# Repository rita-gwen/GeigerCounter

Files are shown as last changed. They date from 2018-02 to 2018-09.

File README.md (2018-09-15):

# GeigerCounter
Firmware and software for a portable Geiger-Mueller counter. 

This project represents a portable, battery powered instrument built around Basic Nano (PIC16F87) microcontroller. The device detects 
radiation particles passing through the detector and keeps total count of them since startup and average over the 
last minute (Counts per Minute). 

This repository includes code of the firmware running on the MCU in the device and a Python application that runs on a PC, 
reads data from the device and shows a real-time plot of the counts. Basic Nano runs an embedded version of MBasic which is used to implement the main loop, power management and display functionality. There are also a couple of assembly procedures for timer ISR that actually gets the counts from the hardware and for low-level display bus handling.

The device successfully passed field testing: I took it on multiple hikes and trips around Cascades and Eastern Washington and it is reliable and performs well - I was able to detect some mildly radioactime granites and verify radiation background change with altitude. 
Features to be implemented in the next version:
 * reduced weight: use LiPO batteries instead of NiMH
 * reduce power consumption (related to the previous item)
 * Improve display visibility in full day light: LCD display is almost invisible in full sun.
 * Add multiple modes of operation: background monitoring, sample measurement
 * add data logging abilities
 * use more advanced CPU, one of ST32 CORTEX-M0 family most probably.

Please ignore the DipTrace schematic and PCB files here, they are outdated. Hardware design files are moved to CircuitMaker (https://circuitmaker.com/Projects/Details/Rita-Chupalov/Geiger). The version of DipTrace I have has too many limitations for this 
project.

Assembly.FCStd is a FreeCAD sketch of the device components fitting into the enclosure.

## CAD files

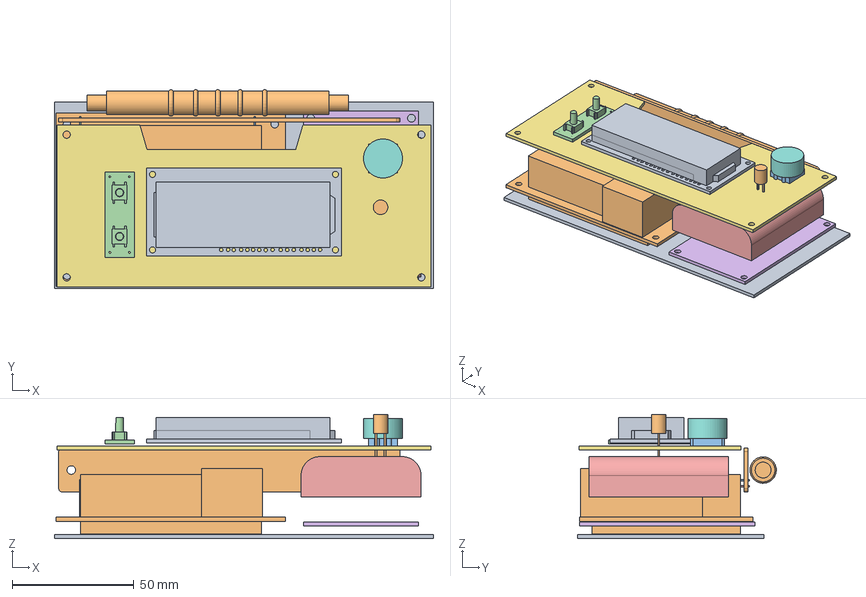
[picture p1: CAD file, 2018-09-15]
Assembly.FCStd
155.4 x 81.5 x 50.9 mm
Chassis
LongPin3
LongPin4
ShortPin3
ShortPin4
FalsePanel
Display
CountLed
DisplayButtonsAssembly

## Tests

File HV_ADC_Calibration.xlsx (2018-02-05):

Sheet: Sheet1
Vtest on 1V scale
Duty | High V | Vtest | ADC | High V | Vtest | ADC
80 | 88 | 400 | 92 | 90.4 | 464 | 91
100 | 94 | 440 | 100 | 98.4 | 504 | 99
120 | 104 | 480 | 106 | 105.6 | 536 | 106
150 | 112 | 520 | 119 | 117.6 | 600 | 119
170 | 116 | 560 | 123 | 122.4 | 624 | 124
200 | 124 | 600 | 130 | 129.2 | 656 | 130
220 | 128 | 640 | 133 | 132 | 672 | 134
250 | 136 | 640 | 139 | 137.6 | 704 | 139
275 | 140 | 680 | 144 | 142.4 | 728 | 144
300 | 144 | 680 | 148 | 144.8 | 736 | 146
325 | 148 | 720 | 151 | 149.6 | 760 | 151

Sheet: Sheet2
Duty period | Vtest | ADC
120 | 824 | 163
150 | 880 | 181
175 | 920 | 187
200 | 1000 | 200
250 | 1060 | 215
300 | 1160 | 230
350 | 1220 | 244
400 | 1290 | 260
450 | 1370 | 272
500 | 1420 | 285
550 | 1460 | 296
600 | 1520 | 309
700 | 1640 | 331
800 | 1760 | 358
900 | 1880 | 381
1000 | 1980 | 404
1100 | 2100 | 427
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

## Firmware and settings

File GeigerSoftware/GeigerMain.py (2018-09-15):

import wx
import json

from GeigerSerial import GeigerSerial
import GeigerSerial as gs
from DataPanel import DataPanel

ID_NEW_FILE = 1
ID_OPEN_FILE = 2
ID_DEVICE_CONNECT = 3   #the range of IDs from 3 to 13 is reserved for multiple devices
ID_DEVICE_DISCONNECT = 14

# TODO:
# Plotting voltages
# Plot scale 
# x axis in date/time units
# add battery level/voltage indicator
# package into a standalone application (with icon)
# replace prints with proper logging
# Add battery charging on/off control
# Add retry to the serial thread to prevent abnormal termination on single read failure
# add ability to add comments/time marks to the data file
#
# Plot scroll - DONE
# vieport position reset on new file - DONE
# Saving to a file - DONE
# Timestamping - DONE
# Show number of data points in the status bar - DONE
# do not keep the full file in memory, only CMP data for the chart - DONE

class AppWindow(wx.Frame):

    def __init__(self):
        wx.Frame.__init__(self, parent = None, title="Geiger Monitor", size=[1000, 1000])
        # Set up the menu
        self.menuBar = wx.MenuBar() 
        fileMenu = wx.Menu()
        fileMenu.Append(ID_NEW_FILE, "New File", "Start new recording file")
        fileMenu.Append(ID_OPEN_FILE, "Open File", "Open a file with previous session data")
        self.menuBar.Append(fileMenu, "File")
        deviceListMenu = wx.Menu()
        i = 0
        for p in GeigerSerial.listPorts():
            deviceListMenu.Append(ID_DEVICE_CONNECT + i, p.device, p.description)
            i += 1
        if deviceListMenu.GetMenuItemCount() == 0:
            deviceListMenu.Append(0, "No devices found").Enable(False)
        deviceMenu = wx.Menu()
        self.connectMenu = deviceMenu.AppendSubMenu(deviceListMenu, "Connect Device>")
        self.disconnectMenu = deviceMenu.Append(ID_DEVICE_DISCONNECT, "Disconnect device")
        self.disconnectMenu.Enable(False)
        self.menuBar.Append(deviceMenu, "Device")
        self.SetMenuBar(self.menuBar)
        #
        #data representation UI
        self.panel = DataPanel(self)
        self.statusBar = self.CreateStatusBar()
        self.statusBar.SetFieldsCount(4)
        self.panel.draw()
        #
        # Events binding
        self.Bind(wx.EVT_MENU, self.OnFileOpen, id=ID_OPEN_FILE)
        self.Bind(wx.EVT_MENU, self.OnNewFile, id=ID_NEW_FILE)
        self.Bind(wx.EVT_MENU_RANGE, self.OnMenuConnect, id = ID_DEVICE_CONNECT, id2 = ID_DEVICE_CONNECT + 10)
        self.Bind(wx.EVT_MENU, self.OnMenuDisconnect, id = ID_DEVICE_DISCONNECT)
        self.Bind(wx.EVT_CLOSE, self.OnExit)
        # Set up the COM
        self.serial = None

    #----------------------------
    # Serial port event handlers
    def OnDeviceData(self, event):
        #print(event.data)
        self.panel.addData(event.data)  
        self.statusBar.SetStatusText("Points:%d" % len(self.panel.cpmData), 3)      

    def OnDeviceConnect(self, event):
        print("Connect event received from ", event.data)
        self.connectMenu.Enable(False)
        self.disconnectMenu.Enable(True)
        self.panel.reset()
        self.statusBar.SetStatusText("Connected to " + event.data, 1)
        self.statusBar.SetStatusText("", 2)

    def OnDeviceDisconect(self, event):
        print("Disconnect event received from ", event.data)
        self.connectMenu.Enable(True)
        self.disconnectMenu.Enable(False)
        for i in range(1,3):
            self.statusBar.SetStatusText("", i) 
    # ------
    # Menu event handlers
    def OnMenuConnect(self, event):
        portList = GeigerSerial.listPorts()
        deviceName = portList[event.Id - ID_DEVICE_CONNECT].device
        print('Device Connect menu selected', deviceName)
        self.serial = GeigerSerial(deviceName, self)
        self.Bind(gs.EVT_SERIAL_OPEN, self.OnDeviceConnect)
        self.Bind(gs.EVT_SERIAL_RX, self.OnDeviceData)
        self.Bind(gs.EVT_SERIAL_CLOSE, self.OnDeviceDisconect)
        self.serial.StartPortThread()

    def OnMenuDisconnect(self, event):
        print('Device Disconnect menu selected')
        self.serial.EndPortThread()

    # Use Case: Open existing data file to examine the data
    def OnFileOpen(self, event):
        print('File Open menu selected')

    # Use case: Specify the file name to save the existing data to. 
    # Can be invoked at any point during or after the recording session
    def OnNewFile(self, event):
        print('New File menu selected')
        with wx.FileDialog(
                None,
                "Save Data As...",
                ".",
                "",
                "Text File|*.txt|JSON Files|*.json|All Files|*",
                wx.FD_SAVE | wx.FD_OVERWRITE_PROMPT) as dlg:
            if dlg.ShowModal() == wx.ID_OK:
                filename = dlg.GetPath()
                self.panel.saveData(filename)
                self.statusBar.SetStatusText("File:"+ filename, 2)

    def OnExit(self, event):
        if self.serial is not None:
            self.serial.EndPortThread()
        self.Destroy()
        



if __name__ == "__main__":
    app = wx.App()
    fr = AppWindow()
    fr.Show()
    app.MainLoop()
    

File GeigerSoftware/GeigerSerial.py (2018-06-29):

import serial
import serial.tools.list_ports
import threading
import wx
import json
from datetime import datetime 

DEVICE_BAUD_RATE = 19200

# ----------------------------------------------------------------------
# Create an own event type, so that GUI updates can be delegated
# this is required as on some platforms only the main thread can
# access the GUI without crashing. wxMutexGuiEnter/wxMutexGuiLeave
# could be used too, but an event is more elegant.

class SerialEvent(wx.CommandEvent):
    def __init__(self, etype, data):
        wx.CommandEvent.__init__(self, commandEventType = etype)
        self.data = data

    def Clone(self):
        # See https://stackoverflow.com/questions/48113110/wxpython-pyserial-and-wx-terminal-thread-fails-to-update-the-gui
        return self.__class__(self.GetEventType(), self.data)

#------------------


SERIAL_RX = wx.NewEventType()
# bind to serial data receive events
EVT_SERIAL_RX = wx.PyEventBinder(SERIAL_RX, 0)

# Serial port opened event
SERIAL_OPEN = wx.NewEventType()
# bind to serial data receive events
EVT_SERIAL_OPEN = wx.PyEventBinder(SERIAL_OPEN, 0)

# Serial port closed event
SERIAL_CLOSE = wx.NewEventType()
# bind to serial data receive events
EVT_SERIAL_CLOSE = wx.PyEventBinder(SERIAL_CLOSE, 0)

#-----------------------------------------------------------------------
# Serial port wrapper
class GeigerSerial():

    #Lists all FTDI devices visible in the system
    @staticmethod
    def listPorts():
        ports = []
        for p in serial.tools.list_ports.comports():
            if p.manufacturer == 'FTDI':
                ports.append(p)
        return ports

    def __init__(self, portName, parent):
        self.port =  None
        self.alive = threading.Event()
        self.parentFrame = parent
        self.portName = portName
        self.thread = None
        self.isOpen = False

    def StartPortThread(self):
        if self.port is not None:
            self.port.close()
        try:
            self.port = serial.Serial(self.portName, DEVICE_BAUD_RATE, timeout=10)
            self.port.dtr = False
        except serial.SerialException as e:
            with wx.MessageDialog(self.parentFrame, str(e), "Serial Port Error", wx.OK | wx.ICON_ERROR) as dlg:
                dlg.ShowModal()
        else:
            self.isOpen = True
            if self.parentFrame is not None:
                event = SerialEvent(SERIAL_OPEN, self.portName)
                wx.PostEvent(self.parentFrame, event)
            else:
                print('Port', self.portName, 'is open')
            self.alive.set()
            self.thread = threading.Thread(target = self.PortThread)
            self.thread.setDaemon(1)
            self.thread.start()

    def EndPortThread(self):
        if self.thread is not None:
            self.alive.clear()
            self.thread.join()
            self.port.close()
            self.thread = None
            self.isOpen = False
            if self.parentFrame is not None:
                event = SerialEvent(SERIAL_CLOSE, self.portName)
                self.parentFrame.GetEventHandler().AddPendingEvent(event)
            else:
                print('Port', self.portName, 'is open')


    def PortThread(self):
        while self.alive.isSet():
            lin = self.port.readline()
            dat = json.loads(lin)
            dat['time'] = datetime.now().strftime('%Y-%m-%d %H:%M:%S.%f')
            if self.parentFrame is not None:
                event = SerialEvent(SERIAL_RX, dat)
                self.parentFrame.GetEventHandler().AddPendingEvent(event)
            #else:
            #    print('Data:', dat)
    
if __name__ == '__main__':  
    ser = GeigerSerial('COM6', None)
    ser.StartPortThread()
    ser.thread.join(60)
    ser.EndPortThread()

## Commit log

2018-01-13 initial commit. Working timer interrupt and counter.
2018-01-15 Count arithmetic problems fixed. Tube fixture drawing added
    [geigerNano.bas]
2018-01-16 LED indicator circuit added to the schematic.
2018-01-20 16 bit count implemented. LED indication added.
2018-01-29 CAD project added
    [Assembly.FCStd]
2018-02-05 Assembly drawing - first complete draft
    [Assembly.FCStd, HV_ADC_Calibration.xlsx]
2018-05-30 Battery management added. JSON output added.
2018-09-15 Added total count and total run time to the display to simplify radioactivity level calculations.
    [Assembly.FCStd]
2018-09-15 minor cleanups
    [Assembly.FCStd]
